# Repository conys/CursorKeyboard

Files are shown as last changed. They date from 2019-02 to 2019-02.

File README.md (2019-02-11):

# CursorKeyboard
HHKB pro2で矢印だけを使うシーンにおいての利便性の向上を図るため，
矢印キーだけのキーボードを設計した．
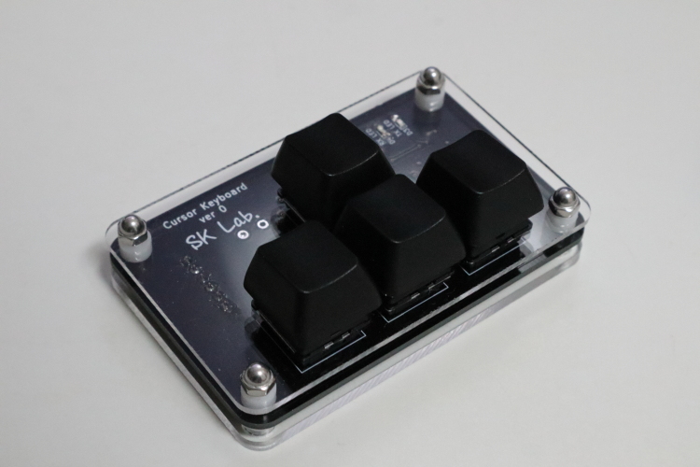
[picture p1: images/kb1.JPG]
kb1


ディレクトリ構成
- /arduino  : pro micro用スケッチ
- /drawing  : キースイッチ固定プレートと底板の図面
- /mykeyboard  : PCBのkicadプロジェクト

回路図
[schema](https://github.com/conys/CursorKeyboard/blob/image/images/schematic.pdf)

# Licence
This software is released under the MIT License, see LICENSE.

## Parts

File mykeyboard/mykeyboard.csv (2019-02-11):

Reference | Value | Footprint | Datasheet
U1 | ATmega32U4-AU | Package_QFP:TQFP-44_10x10mm_P0.8mm | http://ww1.microchip.com/downloads/en/DeviceDoc/Atmel-7766-8-bit-AVR-ATmega16U4-32U4_Datasheet.pdf
SW_RST1 | SW_Push | Button_Switch_THT:SW_PUSH-12mm
SW_LEFT1 | SW_Push | Button_Switch_Keyboard:SW_Cherry_MX1A_1.50u_Plate
SW_DOWN1 | SW_Push | Button_Switch_Keyboard:SW_Cherry_MX1A_1.50u_Plate
SW_RIGHT1 | SW_Push | Button_Switch_Keyboard:SW_Cherry_MX1A_1.50u_Plate
SW_UP1 | SW_Push | Button_Switch_Keyboard:SW_Cherry_MX1A_1.50u_Plate
J1 | USB_B_Micro | Connector_USB:USB_Micro-B_Molex-105017-0001 | ~
R1 | 22 | Resistor_SMD:R_0603_1608Metric_Pad1.05x0.95mm_HandSolder | ~
R2 | 22 | Resistor_SMD:R_0603_1608Metric_Pad1.05x0.95mm_HandSolder | ~
Y1 | 16MHz | Crystal:Crystal_SMD_3215-2Pin_3.2x1.5mm | ~
C4 | 22pF | Capacitor_SMD:C_0603_1608Metric_Pad1.05x0.95mm_HandSolder | ~
C5 | 22pF | Capacitor_SMD:C_0603_1608Metric_Pad1.05x0.95mm_HandSolder | ~
C7 | 1uF | Capacitor_SMD:C_0603_1608Metric_Pad1.05x0.95mm_HandSolder | ~
C6 | 0.1uF | Capacitor_SMD:C_0603_1608Metric_Pad1.05x0.95mm_HandSolder | ~
R4 | 10k | Resistor_SMD:R_0603_1608Metric_Pad1.05x0.95mm_HandSolder | ~
J2 | Conn_01x06 | Connector_JST:JST_EH_S06B-EH_1x06_P2.50mm_Horizontal | ~
C1 | 10uF | Capacitor_SMD:C_0603_1608Metric_Pad1.05x0.95mm_HandSolder | ~
F1 | Polyfuse | Diode_SMD:D_1206_3216Metric_Pad1.42x1.75mm_HandSolder | ~
R3 | 1k | Resistor_SMD:R_0603_1608Metric_Pad1.05x0.95mm_HandSolder | ~
D2 | LED | LED_THT:LED_D3.0mm | ~
D1 | D_Schottky | Diode_SMD:D_1206_3216Metric_Pad1.42x1.75mm_HandSolder | ~
D4 | LED | LED_THT:LED_D3.0mm | ~
R6 | 1k | Resistor_SMD:R_0603_1608Metric_Pad1.05x0.95mm_HandSolder | ~
R5 | 1k | Resistor_SMD:R_0603_1608Metric_Pad1.05x0.95mm_HandSolder | ~
D3 | LED | LED_THT:LED_D3.0mm | ~
C2 | 1uF | Capacitor_SMD:C_0603_1608Metric_Pad1.05x0.95mm_HandSolder | ~
C3 | 0.1uF | Capacitor_SMD:C_0603_1608Metric_Pad1.05x0.95mm_HandSolder | ~

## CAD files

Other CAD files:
drawing/base.dwg
drawing/plate.dwg

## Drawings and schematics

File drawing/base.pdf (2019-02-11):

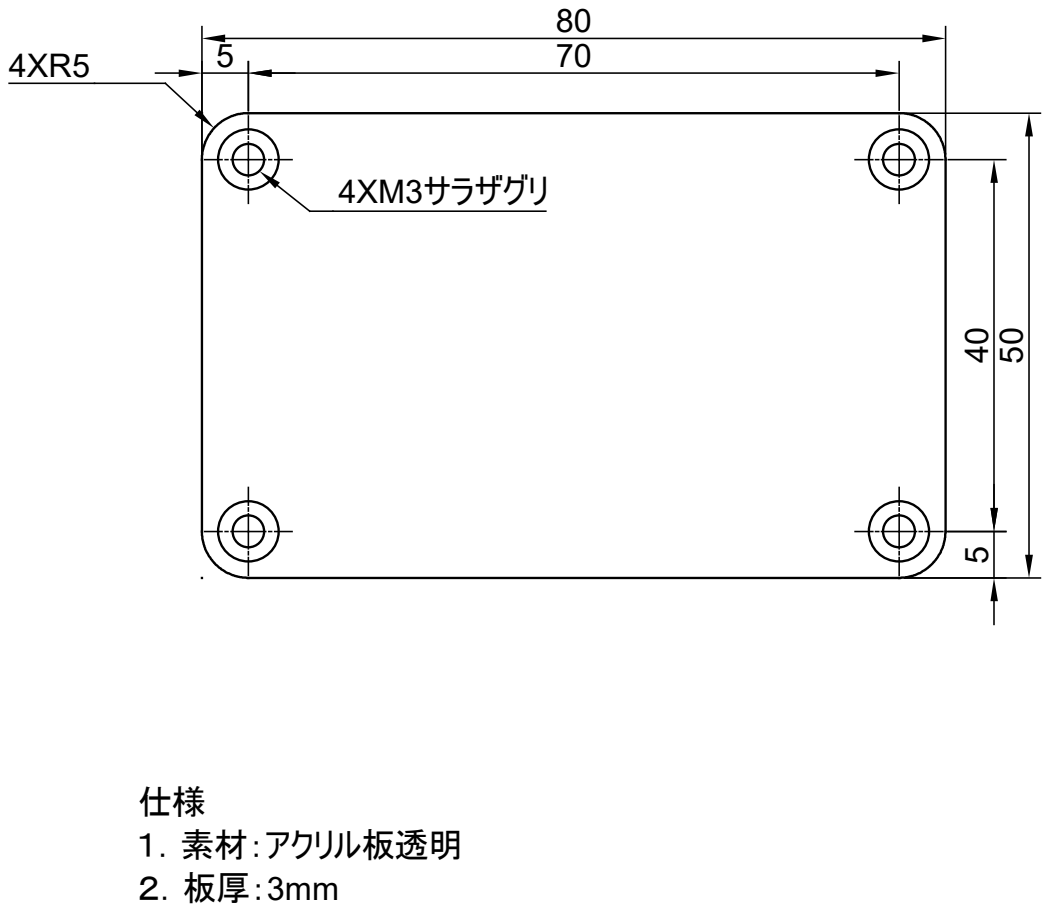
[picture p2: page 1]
4XM3サラザグリ; 仕様 １．素材：アクリル板透明 ２．板厚：3mm

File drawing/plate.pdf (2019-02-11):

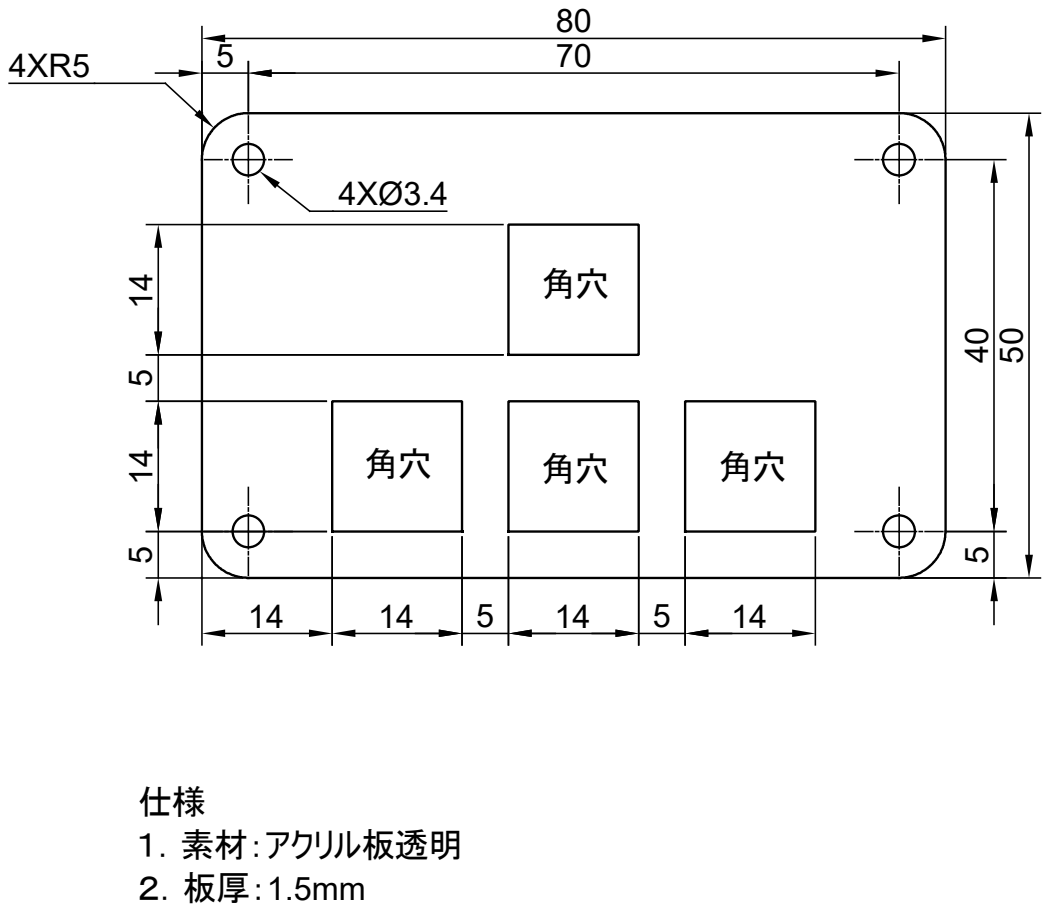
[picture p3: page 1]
仕様 １．素材：アクリル板透明 ２．板厚：1.5mm

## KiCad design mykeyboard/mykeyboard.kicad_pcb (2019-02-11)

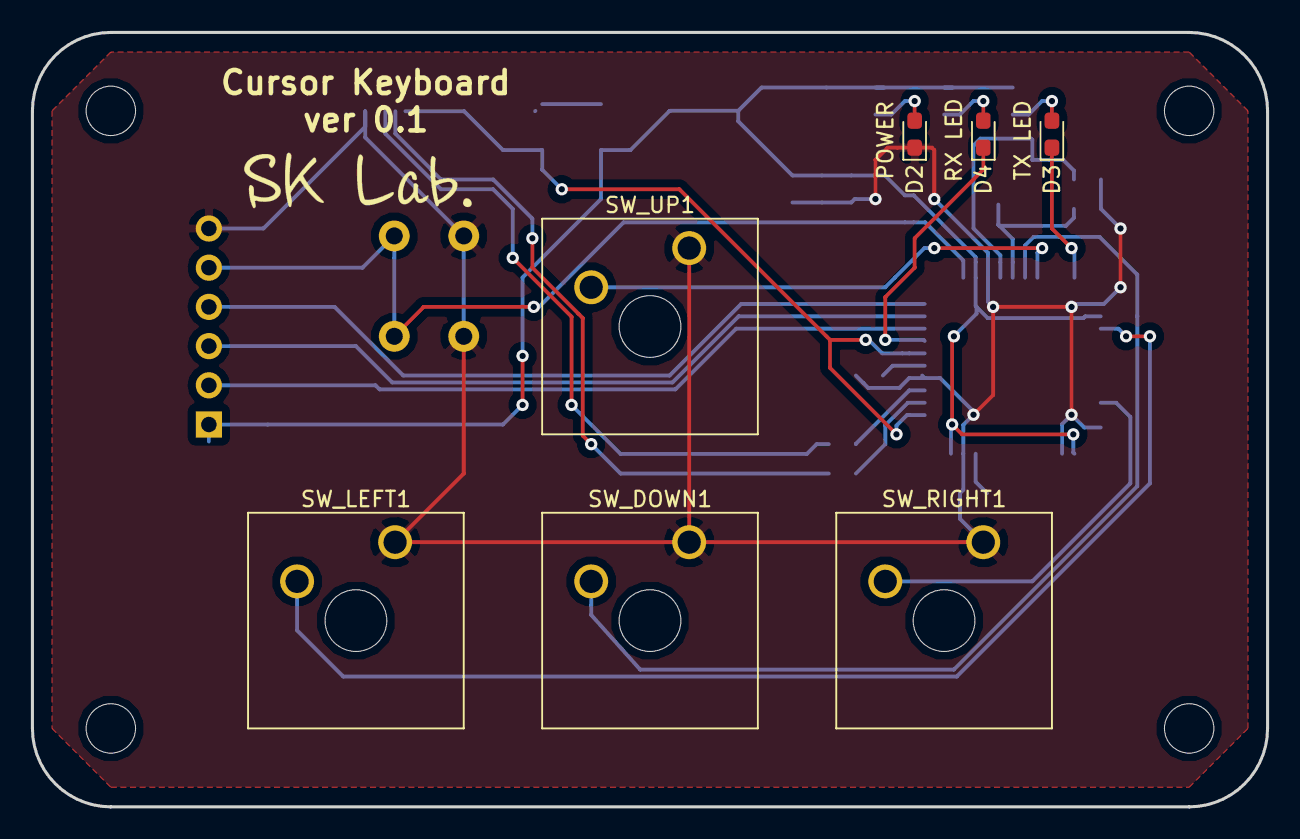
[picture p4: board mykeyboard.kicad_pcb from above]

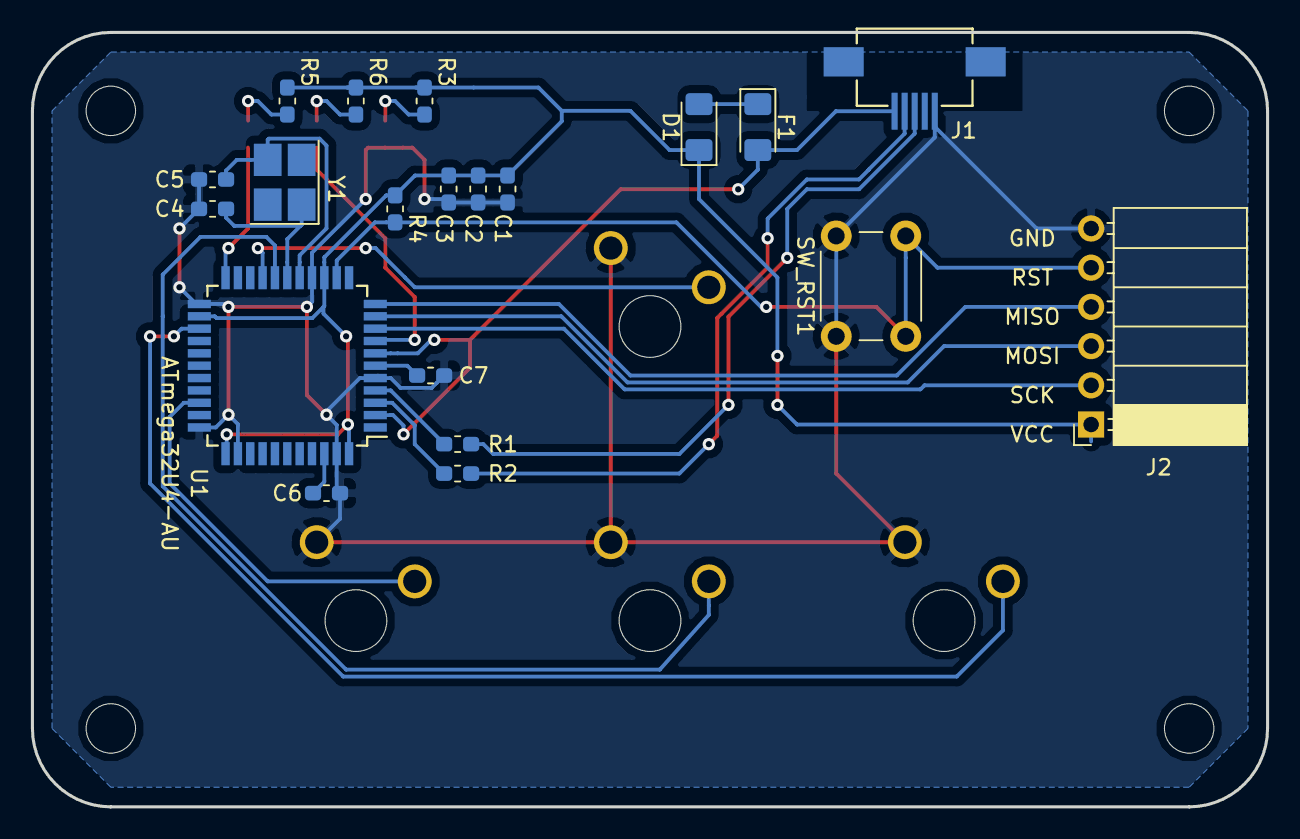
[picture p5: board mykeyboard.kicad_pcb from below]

Board: 2 copper layers, 80.0 x 50.2 mm, 27 parts (20 on the bottom side), 25 nets.

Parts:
C1: 10uF; C_0603_1608Metric_Pad1.05x0.95mm_HandSolder
C2, C7: 1uF; C_0603_1608Metric_Pad1.05x0.95mm_HandSolder
C3, C6: 0.1uF; C_0603_1608Metric_Pad1.05x0.95mm_HandSolder
C4, C5: 22pF; C_0603_1608Metric_Pad1.05x0.95mm_HandSolder
D1: D_Schottky; D_1206_3216Metric_Pad1.42x1.75mm_HandSolder
D2, D3, D4: LED; LED_0603_1608Metric_Pad1.05x0.95mm_HandSolder
F1: Polyfuse; D_1206_3216Metric_Pad1.42x1.75mm_HandSolder
J1: USB_B_Micro; USB_B_Micro_hirose_reverse
J2: Conn_01x06; PinSocket_1x06_P2.54mm_Horizontal
R1, R2: 22; R_0603_1608Metric_Pad1.05x0.95mm_HandSolder
R3, R5, R6: 1k; R_0603_1608Metric_Pad1.05x0.95mm_HandSolder
R4: 10k; R_0603_1608Metric_Pad1.05x0.95mm_HandSolder
SW_DOWN1: SW_Push; SW_Cherry_MX1A_1.00u_Plate
SW_LEFT1: SW_Push; SW_Cherry_MX1A_1.00u_Plate
SW_RIGHT1: SW_Push; SW_Cherry_MX1A_1.00u_Plate
SW_RST1: SW_Push; SW_PUSH_6mm
SW_UP1: SW_Push; SW_Cherry_MX1A_1.00u_Plate
U1: ATmega32U4-AU; TQFP-44_10x10mm_P0.8mm
Y1: 16MHz; Crystal_SMD_SeikoEpson_FA238-4Pin_3.2x2.5mm_HandSoldering

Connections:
/D2: SW_UP1.2, U1.19
/D3: SW_DOWN1.2, U1.18
/D4: SW_LEFT1.2, U1.25
/D5: SW_RIGHT1.2, U1.31
/D+: R1.2, U1.4
/D-: R2.2, U1.3
/MISO: J2.4, U1.11
/MOSI: J2.3, U1.10
/RST: J2.5, R4.2, SW_RST1.2, U1.13
/SCK: J2.2, U1.9
/UVCC: F1.2, J1.1, U1.2, U1.7
/VCC: C1.1, C2.1, C3.1, D1.1, J2.1, R3.1, R4.1, R5.1, R6.1, U1.14, U1.24, U1.34, U1.44
GND: C1.2, C2.2, C3.2, C4.2, C5.2, C6.2, C7.2, D2.1, J1.5, J2.6, SW_DOWN1.1, SW_LEFT1.1, SW_RIGHT1.1, SW_RST1.1, SW_UP1.1, U1.5, U1.15, U1.23, U1.33, U1.35, U1.43
unnamed: C4.1, U1.17, Y1.1
unnamed: C5.1, U1.16, Y1.2
unnamed: C6.1, U1.42
unnamed: C7.1, U1.6
unnamed: D1.2, F1.1
unnamed: D2.2, R3.2
unnamed: D3.1, U1.22
unnamed: D3.2, R5.2
unnamed: D4.1, U1.8
unnamed: D4.2, R6.2
unnamed: J1.2, R2.1
unnamed: J1.3, R1.1

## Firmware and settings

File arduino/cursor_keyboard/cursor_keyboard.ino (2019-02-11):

#include <Keyboard.h>

const int UpPin = 2;
const int DownPin = 3;
const int LeftPin = 4;
const int RightPin = 5;

// スイッチ状態変数
boolean UpS = HIGH; //上
boolean DownS = HIGH; //下
boolean LeftS = HIGH; //左
boolean RightS = HIGH; //右

// スイッチ状態1つ前
boolean UpS2 = HIGH; //上
boolean DownS2 = HIGH; //下
boolean LeftS2 = HIGH; //左
boolean RightS2 = HIGH; //右

void setup() {
  Keyboard.begin();
  pinMode(UpPin,    INPUT_PULLUP);
  pinMode(DownPin,  INPUT_PULLUP);
  pinMode(LeftPin,  INPUT_PULLUP);
  pinMode(RightPin, INPUT_PULLUP);  
}

void loop() {
  // ボタン状態保存
  UpS2 = UpS;
  DownS2 = DownS;
  LeftS2 = LeftS;
  RightS2 = RightS;
  
  UpS = digitalRead(UpPin);
  DownS = digitalRead(DownPin);
  LeftS = digitalRead(LeftPin);
  RightS = digitalRead(RightPin);

  digitalWrite(17, HIGH);

  // UpPin 上ボタン
  if(UpS == LOW and UpS2 == HIGH){
    Keyboard.press(KEY_UP_ARROW);
    
    digitalWrite(17, LOW);
  }
  else if(UpS == HIGH){
    Keyboard.release(KEY_UP_ARROW);
  }
  
  // DownPin 下ボタン
  if(DownS == LOW and DownS2 == HIGH){
    Keyboard.press(KEY_DOWN_ARROW);
        
    digitalWrite(17, LOW);
  }
  else if(DownS == HIGH){
    Keyboard.release(KEY_DOWN_ARROW);
  }
  
  // LeftPin 左ボタン
  if(LeftS == LOW and LeftS2 == HIGH){
    Keyboard.press(KEY_LEFT_ARROW);

    digitalWrite(17, LOW);
  }
  else if(LeftS == HIGH){
    Keyboard.release(KEY_LEFT_ARROW);
  }
  
  // RightPin 右ボタン
  if(RightS == LOW and RightS2 == HIGH){
    Keyboard.press(KEY_RIGHT_ARROW);

    digitalWrite(17, LOW);   
  }
  else if(RightS == HIGH) {
    Keyboard.release(KEY_RIGHT_ARROW);
  }

  delay(100);
}
